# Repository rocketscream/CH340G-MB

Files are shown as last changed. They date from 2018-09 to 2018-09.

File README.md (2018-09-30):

# WCH CH340G USB-Serial Adapter Board
WCH CH340G board is a cost effective USB-serial adapter with the ever familiar FTDI 6-pin female header which you can use with Arduino Pro or Pro Mini for both 3.3V and 5V version. The board supports both 5V and 3.3V IO voltage level through a slide switch. The board also has an on-board 3.3V LDO regulator to provide up to 250 mA of output current. The VCC pin on the 6-pin female header can be selectable to be either 5V or 3.3V. A green and red LED indicate TX & RX activity of the board. A resettable 0.5A fuse is included to provide protection to the USB port from over current. All other pins like RTS, DTR, DCD, RI, DSR, and CTS are made available for use on the side of the board.

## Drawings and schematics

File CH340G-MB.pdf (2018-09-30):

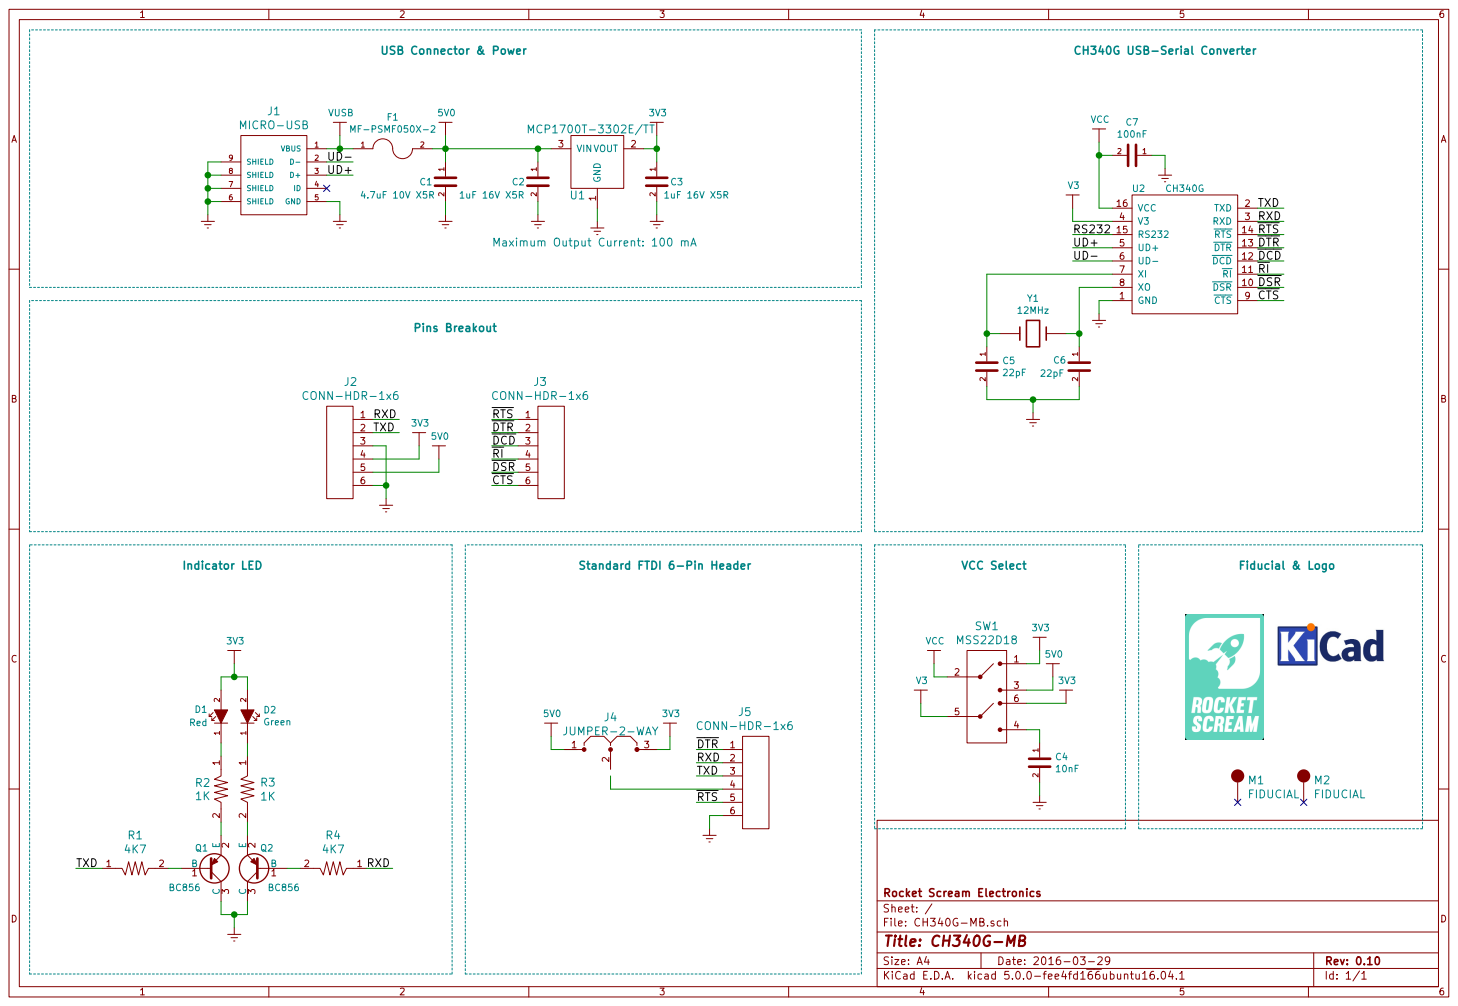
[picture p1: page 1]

Maximum Output Current: 100 mA

File: CH340G-MB.sch Sheet: / Rocket Scream Electronics

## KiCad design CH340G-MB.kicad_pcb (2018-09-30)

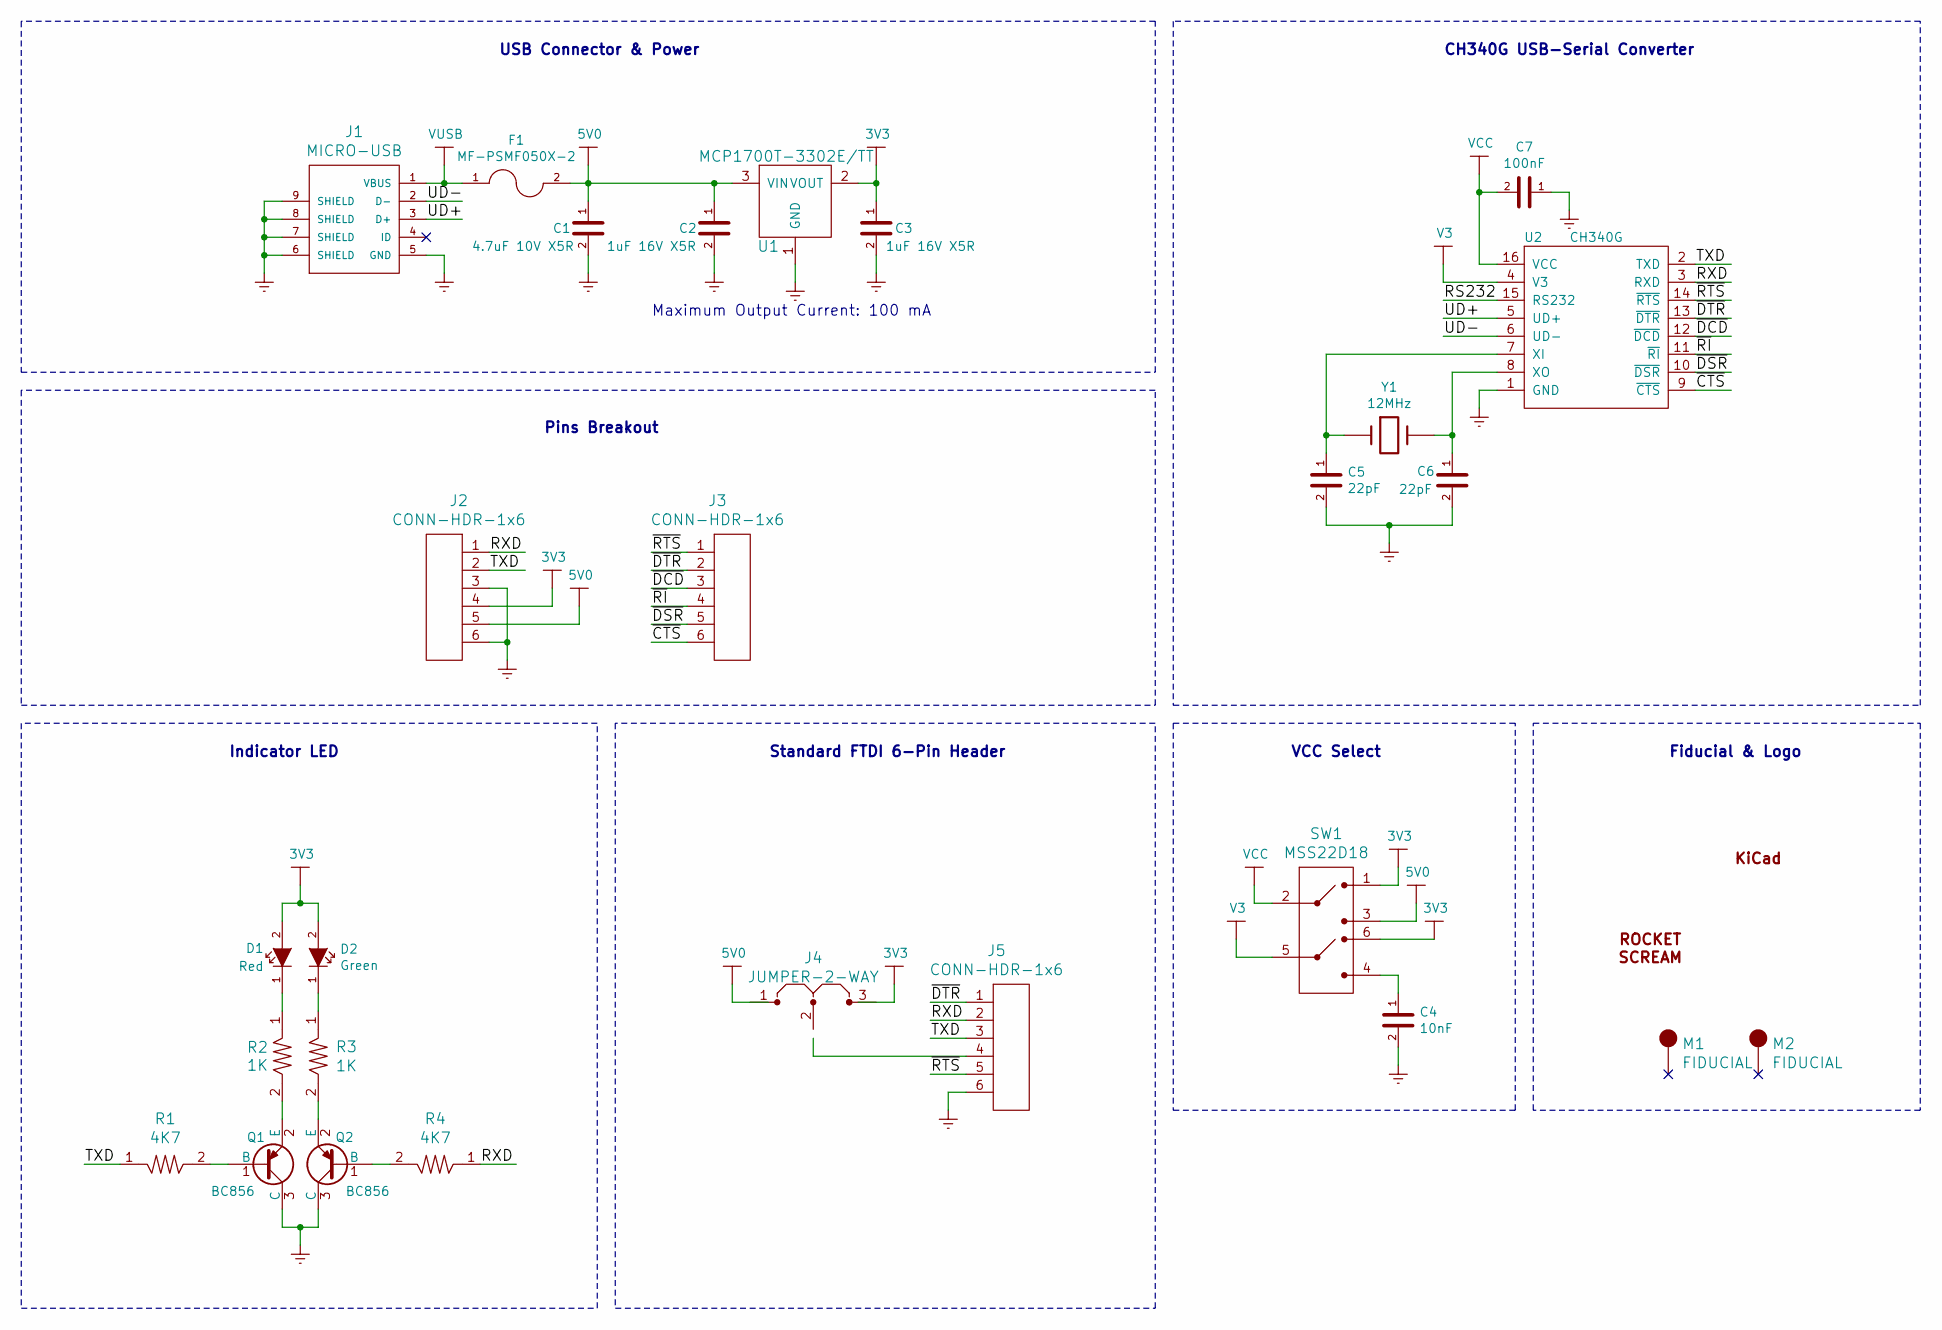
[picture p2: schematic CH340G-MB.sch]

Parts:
C1: 4.7uF 10V X5R; CAP-0603
C2, C3: 1uF 16V X5R; CAP-0603
C4: 10nF; CAP-0603
C5, C6: 22pF; CAP-0603
C7: 100nF; CAP-0603
D1: Red; LED-0603
D2: Green; LED-0603
F1: MF-PSMF050X-2; MF-PSMF020X
J1: MICRO-USB
J2, J3: CONN-HDR-1x6; HDR_1x6_Pitch2.54mm_WithoutSilk
J4: JUMPER-2-WAY; JUMPER-2-WAY-SMD
J5: CONN-HDR-1x6; RCP_1x6_Pitch2.54mm_RightAngle
LOGO1: LOGO-ROCKET-SCREAM; LOGO-ROCKET-SCREAM_Vertical_XSmall
LOGO2: LOGO-KICAD; LOGO-KICAD_XSmall
M1, M2: FIDUCIAL; FIDUCIAL-1MM
Q1, Q2: BC856; SOT-23
R1, R4: 4K7; RES-0603
R2, R3: 1K; RES-0603
SW1: MSS22D18
U1: MCP1700T-3302E/TT; SOT-23
U2: CH340G; SOP-16_150mil
Y1: 12MHz; ABM3

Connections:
3V3: C3.1, D1.2 (A), D2.2 (A), J2.4, J4.3, SW1.1, SW1.6, U1.2 (VOUT)
5V0: C1.1, C2.1, F1.2, J2.5, J4.1, SW1.3, U1.3 (VIN)
/RS232: U2.15 (RS232)
/RXD: J2.1, J5.2, R4.1, U2.3 (RXD)
/TXD: J2.2, J5.3, R1.1, U2.2 (TXD)
/UD+: J1.3 (D+), U2.5 (UD+)
/UD-: J1.2 (D-), U2.6 (UD-)
/~CTS: J3.6, U2.9 (~CTS)
/~DCD: J3.3, U2.12 (~DCD)
/~DSR: J3.5, U2.10 (~DSR)
/~DTR: J3.2, J5.1, U2.13 (~DTR)
/~RI: J3.4, U2.11 (~RI)
/~RTS: J3.1, J5.5, U2.14 (~RTS)
GND: C1.2, C2.2, C3.2, C4.2, C5.2, C6.2, C7.1, J1.5 (GND), J1.6 (SHIELD), J1.7 (SHIELD), J1.8 (SHIELD), J1.9 (SHIELD), J2.3, J2.6, J5.6, Q1.3 (C), Q2.3 (C), U1.1 (GND), U2.1 (GND)
unnamed: C4.1, SW1.4
unnamed: C5.1, U2.7 (XI), Y1.1
unnamed: C6.1, U2.8 (XO), Y1.2
unnamed: D1.1 (K), R2.1
unnamed: D2.1 (K), R3.1
unnamed: J4.2, J5.4
unnamed: Q1.1 (B), R1.2
unnamed: Q1.2 (E), R2.2
unnamed: Q2.1 (B), R4.2
unnamed: Q2.2 (E), R3.2
V3: SW1.5, U2.4 (V3)
VCC: C7.2, SW1.2, U2.16 (VCC)
VUSB: F1.1, J1.1 (VBUS)

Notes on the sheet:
Indicator LED
Standard FTDI 6-Pin Header
VCC Select
Fiducial & Logo
Pins Breakout
USB Connector & Power
Maximum Output Current: 100 mA
CH340G USB-Serial Converter

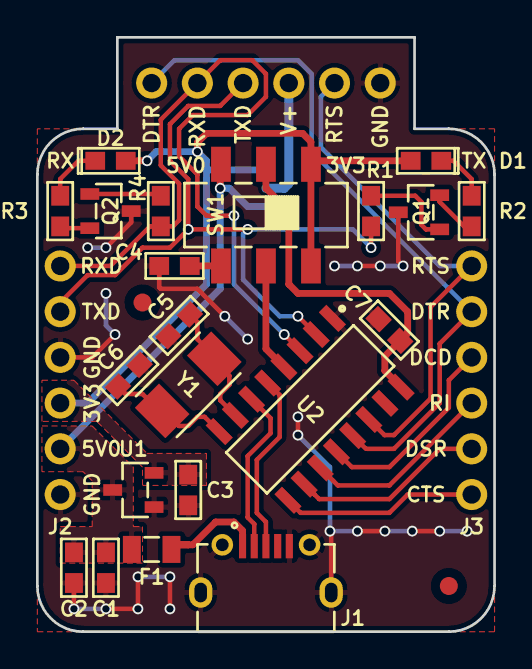
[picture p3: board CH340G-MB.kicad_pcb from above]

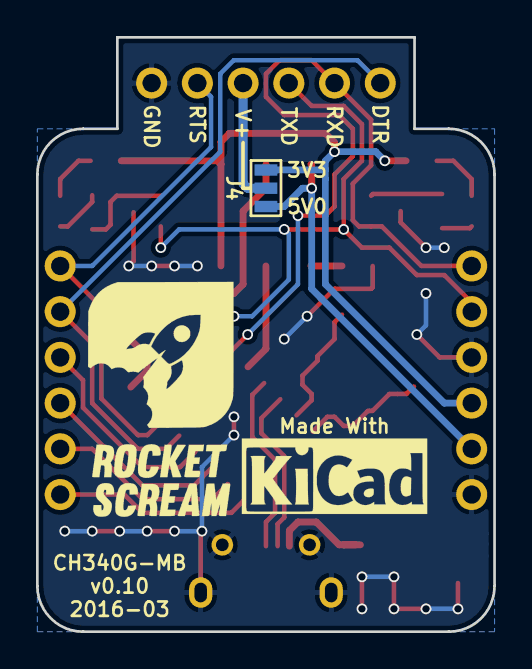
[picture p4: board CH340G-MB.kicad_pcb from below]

Board: 2 copper layers, 25.4 x 33.0 mm, 29 parts (3 on the bottom side), 26 nets.
